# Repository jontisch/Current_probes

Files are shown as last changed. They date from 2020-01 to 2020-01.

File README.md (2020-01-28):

# hall-effect-sensor
A Hall Effect measurement system for measuring power/amperage for graphing

This uses the circuit described in the eagle/gerber directory. 
We've used dirtypcbs.com to make them (http://dirtypcbs.com/view.php?share=27748&accesskey=)

The code used is in arduino/src
It is dependant on 
https://github.com/sirleech/TrueRandom
https://github.com/openenergymonitor/EmonLib 
https://github.com/ntruchsess/arduino_uip (which in turn is patched to support sending DHCP Client Identification which is why it is included in arduino/src)

Hall effect sensors used are SCT-013-000.

---------------------------------------------

IMPORTANT!!

When running on a 2k SRAM AVR (most arduinos) you will need to tweak the serial RX/TX buffers.
This can be found in Arduino/hardware/arduino/avr/cores/arduino/HardwareSerial.h

Just change 
#define SERIAL_TX_BUFFER_SIZE 64
to 
#define SERIAL_TX_BUFFER_SIZE 8

and 

#define SERIAL_RX_BUFFER_SIZE 64
to
#define SERIAL_RX_BUFFER_SIZE 8

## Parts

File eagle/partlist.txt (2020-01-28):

Partlist

Exported from current.sch at 2016-11-06 10:24

EAGLE Version 7.7.0 Copyright (c) 1988-2016 CadSoft

Assembly variant: 

Part     Value              Device             Package               Library             Sheet

C1       10uF               CAP_POLPTH1        CPOL-RADIAL-100UF-25V SparkFun-Passives   1
C2       10uF               CAP_POLPTH2        CPOL-RADIAL-10UF-25V  SparkFun-Capacitors 1
C3       22pF               C5/2.5             C5B2.5                capacitor-wima      1
C4       22pF               C5/2.5             C5B2.5                capacitor-wima      1
C5       10uF               CAP_POLPTH1        CPOL-RADIAL-100UF-25V SparkFun-Passives   1
C6       10uF               CAP_POLPTH1        CPOL-RADIAL-100UF-25V SparkFun-Passives   1
H1       MOUNT-PAD-ROUND3.6 MOUNT-PAD-ROUND3.6 3,6-PAD               holes               1
J1       USB-MICROB         USB-MICROB         USB-MICROB            SparkFun-Connectors 1
J2       3-pol              AUDIO-JACKPTH      AUDIO-JACK            SparkFun-Connectors 1
J3       3-pol              AUDIO-JACKPTH      AUDIO-JACK            SparkFun-Connectors 1
J4       3-pol              AUDIO-JACKPTH      AUDIO-JACK            SparkFun-Connectors 1
LED1     5mm green          LED5MM             LED5MM                led                 1
Q1       16MHz              XTAL/S             QS                    special             1
R1       33                 R-US_0204/5        0204/5                resistor            1
R2       10K                R-US_0204/5        0204/5                resistor            1
R3       10K                R-US_0204/5        0204/5                resistor            1
R4       33                 R-US_0204/5        0204/5                resistor            1
R5       10K                R-US_0204/5        0204/5                resistor            1
R6       10K                R-US_0204/5        0204/5                resistor            1
R7       33                 R-US_0204/5        0204/5                resistor            1
R8       10K                R-US_0204/5        0204/5                resistor            1
R9       10K                R-US_0204/5        0204/5                resistor            1
R10      10K                R-US_0204/5        0204/5                resistor            1
R11      10K                R-US_0204/5        0204/5                resistor            1
R12      10K                R-US_0204/5        0204/5                resistor            1
R13      180                R-US_0204/5        0204/5                resistor            1
R14      100                R-US_0204/5        0204/5                resistor            1
R15      470                R-US_0204/5        0204/5                resistor            1
R16      100                R-US_0204/5        0204/5                resistor            1
R17      10K                R-US_0204/5        0204/5                resistor            1
R18      10K                R-US_0204/5        0204/5                resistor            1
SV1                         MA03-2             MA03-2                con-lstb            1
SV2                         MA05-2             MA05-2                con-lstb            1
SV3      rgb-led            MA04-1             MA04-1                con-lstb            1
SW1                         SW_DIP-2           EDG-02                special             1
U1       ATMEGA328P_PDIP    ATMEGA328P_PDIP    DIL28-3               SparkFun-DigitalIC  1

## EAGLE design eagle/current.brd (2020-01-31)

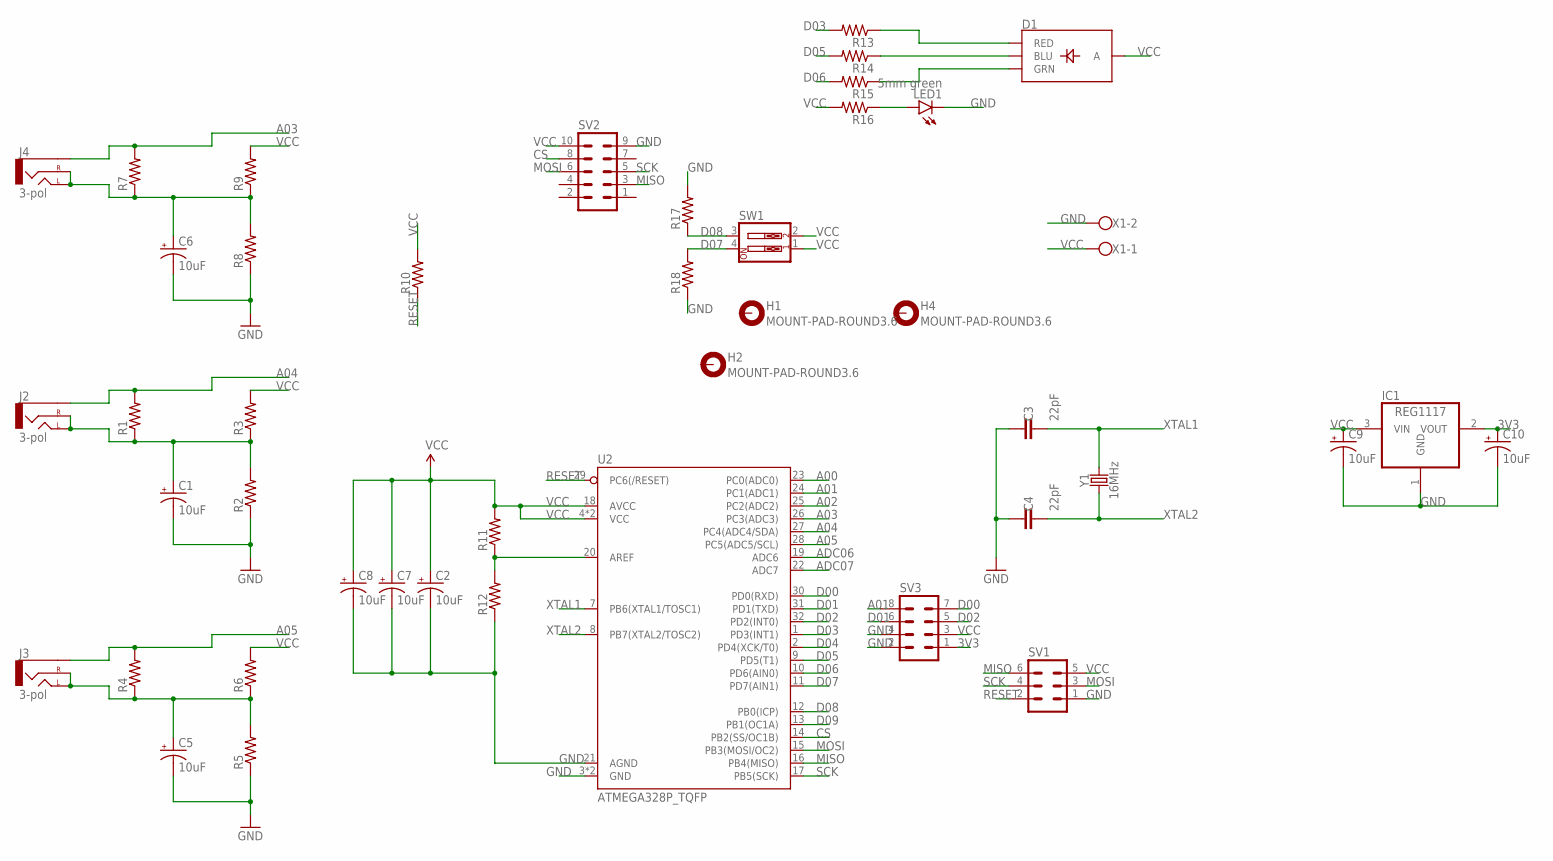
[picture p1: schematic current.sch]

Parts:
C1, C2, C5, C6, C7, C8, C9, C10: 10uF; EIA3216
C3, C4: 22pF; 0805
D1: LED-RGB-CASMD; LED-TRICOLOR-SMD
H1, H2, H4: MOUNT-PAD-ROUND3.6; 3,6-PAD
IC1: REG1117; SOT223
J2, J3, J4: 3-pol; AUDIO-JACK
LED1: 5mm green; CHIPLED_0805
R1, R2, R3, R4, R5, R6, R7, R8, R9, R10, R11, R12, R13, R14, R15, R16, R17, R18: 0805
SV1: MA03-2
SV2: MA05-2
SV3: MA04-2
SW1: SW_DIP-2; EDG-02
U2: ATMEGA328P_TQFP; TQFP32-08
X1: W237-102
Y1: 16MHz; CRYSTAL-SMD-3.2X2.5MM

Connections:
3V3: C10.+, IC1.2 (VOUT), SV3.1
A00: U2.23 (PC0(ADC0))
A01: SV3.8, U2.24 (PC1(ADC1))
A02: U2.25 (PC2(ADC2))
A03: J4.SLEEVE, R7.2, U2.26 (PC3(ADC3))
A04: J2.SLEEVE, R1.2, U2.27 (PC4(ADC4/SDA))
A05: J3.SLEEVE, R4.2, U2.28 (PC5(ADC5/SCL))
ADC06: U2.19 (ADC6)
ADC07: U2.22 (ADC7)
CS: SV2.8, U2.14 (PB2(SS/OC1B))
D00: SV3.7, U2.30 (PD0(RXD))
D01: SV3.6, U2.31 (PD1(TXD))
D02: SV3.5, U2.32 (PD2(INT0))
D03: R13.2, U2.1 (PD3(INT1))
D04: U2.2 (PD4(XCK/T0))
D05: R14.2, U2.9 (PD5(T1))
D06: R15.2, U2.10 (PD6(AIN0))
D07: R18.2, SW1.4, U2.11 (PD7(AIN1))
D08: R17.1, SW1.3, U2.12 (PB0(ICP))
D09: U2.13 (PB1(OC1A))
GND: C1.-, C2.-, C3.1, C4.1, C5.-, C6.-, C7.-, C8.-, C9.-, C10.-, IC1.1 (GND), LED1.C, R2.1, R5.1, R8.1, R12.1, R17.2, R18.1, SV1.1, SV2.9, SV3.2, SV3.4, U2.3 (GND), U2.5 (GND), U2.21 (AGND), X1.2
MISO: SV1.6, SV2.3, U2.16 (PB4(MISO))
MOSI: SV1.3, SV2.6, U2.15 (PB3(MOSI/OC2))
unnamed: C5.+, J3.RING (RIGHT), J3.TIP (LEFT), R4.1, R5.2, R6.1
unnamed: C1.+, J2.RING (RIGHT), J2.TIP (LEFT), R1.1, R2.2, R3.1
unnamed: C6.+, J4.RING (RIGHT), J4.TIP (LEFT), R7.1, R8.2, R9.1
unnamed: D1.R (RED), R13.1
unnamed: R11.1, R12.2, U2.20 (AREF)
unnamed: D1.B (BLU), R14.1
unnamed: D1.G (GRN), R15.1
unnamed: LED1.A, R16.1
RESET: R10.1, SV1.2, U2.29 (PC6(/RESET))
SCK: SV1.4, SV2.5, U2.17 (PB5(SCK))
VCC: C2.+, C7.+, C8.+, C9.+, D1.A, IC1.3 (VIN), R3.2, R6.2, R9.2, R10.2, R11.2, R16.2, SV1.5, SV2.10, SV3.3, SW1.1, SW1.2, U2.4 (VCC), U2.6 (VCC), U2.18 (AVCC), X1.1
XTAL1: C3.2, U2.7 (PB6(XTAL1/TOSC1)), Y1.3 (2)
XTAL2: C4.2, U2.8 (PB7(XTAL2/TOSC2)), Y1.1

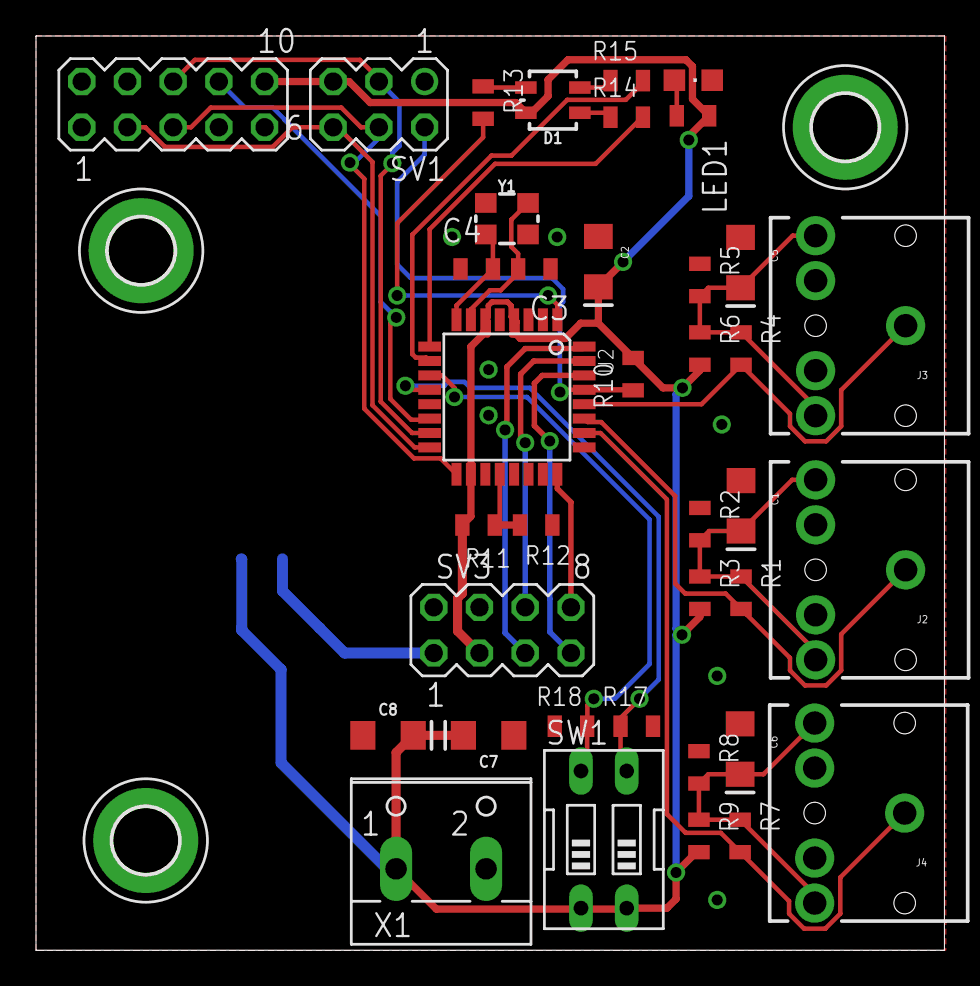
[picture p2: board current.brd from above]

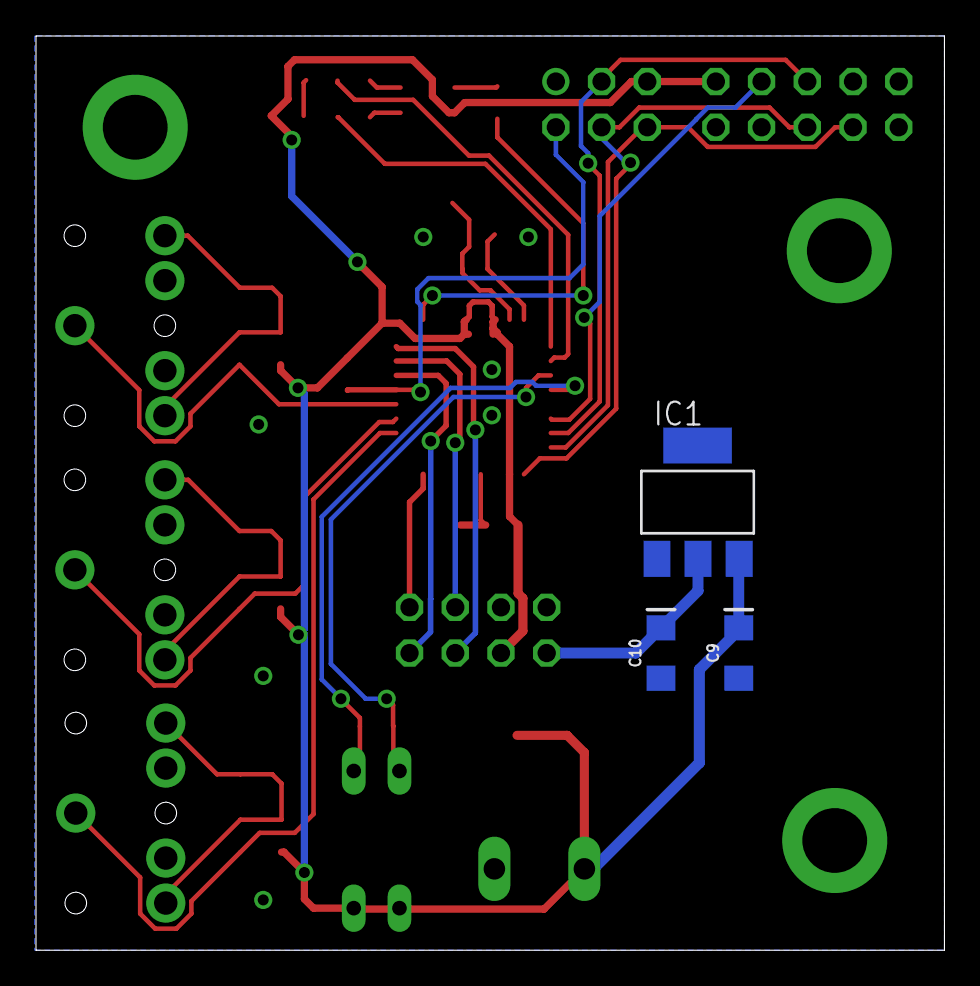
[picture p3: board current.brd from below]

Board: 2 copper layers, 50.5 x 50.8 mm, 44 parts (3 on the bottom side), 30 nets.

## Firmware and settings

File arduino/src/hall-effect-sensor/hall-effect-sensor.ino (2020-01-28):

#include <Dhcp.h>
#include <Dns.h>
#include <avr/pgmspace.h>
#include <ethernet_comp.h>
#include <UIPClient.h>
#include <UIPEthernet.h>
#include <UIPServer.h>
#include <UIPUdp.h>
#include <EmonLib.h>
#include <EEPROM.h>
#include <TrueRandom.h>
// Sample data for the mac address generation
#define samplePin 0
// Calibration value for the SCT-013-000s
#define ACcalibrationValue 22
#define DCcalibrationValue 22
#define voltage 230
#define ERROR (RGB){ HIGH, LOW, LOW };
#define LOADING (RGB){ HIGH, HIGH, LOW };
#define OK (RGB){ LOW, HIGH, LOW };
#define F_CPU 16000000UL

struct RGB {
  byte r;
  byte g;
  byte b;
};

typedef struct {
  EnergyMonitor one;
  EnergyMonitor two;
  EnergyMonitor three;
} Sensors;

RGB LED = ERROR;
static byte mac[6] = { 0x02, 0x00, 0x00, 0x00, 0x00, 0x00 };
unsigned long previous = millis();
unsigned long current = millis();

Sensors sensors;
EthernetServer server = EthernetServer(80);

void generateMacAddress() {
  if (EEPROM.read(1) == '#') {
    for (int i = 4; i < 6; i++) {
      mac[i] = EEPROM.read(i);
    }
  } else {
    randomSeed(analogRead(samplePin));
    for (int i = 4; i < 6; i++) {
      mac[i] = random(0, 255);
      EEPROM.write(i, mac[i]);
    }
    EEPROM.write(1, '#');
  }
}

void initializeRGBdiode() {
  pinMode(3, OUTPUT);
  digitalWrite(3, LOW);
  pinMode(5, OUTPUT);
  digitalWrite(5, LOW);
  pinMode(6, OUTPUT);
  digitalWrite(6, LOW);
  setRGBLEDColor();
}

void setRGBLEDColor() {
  digitalWrite(3, LED.r);
  digitalWrite(5, LED.g);
  digitalWrite(6, LED.b);
}

void blinkRGB() {
  for (int i = 0; i < 10; i++) {
    if (i % 2 == 0) {
      digitalWrite(3, HIGH);
      digitalWrite(5, HIGH);
      digitalWrite(6, HIGH);
    } else {
      digitalWrite(3, LOW);
      digitalWrite(5, LOW);
      digitalWrite(6, LOW);
    }
    delay(100);
  }
}

void setup () {
  Serial.begin(57600);
  initializeRGBdiode();
  pinMode(7, INPUT);
  pinMode(8, INPUT);
  if (digitalRead(7) && digitalRead(8)) { 
    for (int i = 0 ; i < EEPROM.length() ; i++) {
      EEPROM.write(i, 0);
    }
    blinkRGB();
  }

  generateMacAddress();

  if (Ethernet.begin(mac) == 0) {
    LED = ERROR;
    setRGBLEDColor();
  }
  server.begin();

  configureSensors();
  LED = OK;
  setRGBLEDColor();
}

void configureSensors() {
  if (digitalRead(7) && !digitalRead(8)) {
    sensors.one.current(3, DCcalibrationValue);
    sensors.two.current(5, DCcalibrationValue);
    sensors.three.current(4, DCcalibrationValue);
  } else {
    sensors.one.current(3, ACcalibrationValue);
    sensors.two.current(5, ACcalibrationValue);
    sensors.three.current(4, ACcalibrationValue);
  }
}

int readSensor(int sensor) {
  switch (sensor) {
    case 1:
      return sensors.one.calcIrms(1480) * voltage;
      break;
    case 2:
      return sensors.two.calcIrms(1480) * voltage;
      break;
    case 3:
      return sensors.three.calcIrms(1480) * voltage;
      break;
  }
}
char* intToCharFloat(int value) {
  char *buf = (char *) malloc(sizeof(char) * 6);
  dtostrf(value/100.0, 4, 2, buf);
  return buf;
}

void loop() {
  /* Ugly hack to solve that it goes bad after >2000 seconds of requests */
  current = millis();
  if (current-previous > 30000) {
    Enc28J60.init(mac);
    previous = millis();
  }
  setRGBLEDColor();
  Ethernet.maintain();

  EthernetClient client = server.available();
  if (client == true) {
    char reply[110];
    char* sensor1_value = intToCharFloat(readSensor(1));
    char* sensor2_value = intToCharFloat(readSensor(2));
    char* sensor3_value = intToCharFloat(readSensor(3));
    
    server.println(F("HTTP/1.1 200 OK\r\nContent-Type: text/plain\r\nConnection: Closed\r\n"));
    sprintf(reply, "uptime %lu\ncurrent{sensor=\"1\"} %s\ncurrent{sensor=\"2\"} %s\ncurrent{sensor=\"3\"} %s\n", millis()/1000, sensor1_value, sensor2_value, sensor3_value);
    server.print(reply);
    client.stop();
    free(sensor1_value);
    free(sensor2_value);
    free(sensor3_value);
  }
}

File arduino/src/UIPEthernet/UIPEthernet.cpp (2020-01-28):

/*
 UIPEthernet.cpp - Arduino implementation of a uIP wrapper class.
 Copyright (c) 2013 Norbert Truchsess <norbert.truchsess@t-online.de>
 All rights reserved.

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
 You should have received a copy of the GNU General Public License
 along with this program.  If not, see <http://www.gnu.org/licenses/>.
  */

#include <Arduino.h>
#include "UIPEthernet.h"
#include "utility/Enc28J60Network.h"

#if(defined UIPETHERNET_DEBUG || defined UIPETHERNET_DEBUG_CHKSUM)
#include "HardwareSerial.h"
#endif

#include "UIPUdp.h"

extern "C"
{
#include "utility/uip-conf.h"
#include "utility/uip.h"
#include "utility/uip_arp.h"
#include "utility/uip_timer.h"
}

#define ETH_HDR ((struct uip_eth_hdr *)&uip_buf[0])

memhandle UIPEthernetClass::in_packet(NOBLOCK);
memhandle UIPEthernetClass::uip_packet(NOBLOCK);
uint8_t UIPEthernetClass::uip_hdrlen(0);
uint8_t UIPEthernetClass::packetstate(0);

IPAddress UIPEthernetClass::_dnsServerAddress;
DhcpClass* UIPEthernetClass::_dhcp(NULL);

unsigned long UIPEthernetClass::periodic_timer;

// Because uIP isn't encapsulated within a class we have to use global
// variables, so we can only have one TCP/IP stack per program.

UIPEthernetClass::UIPEthernetClass()
{
}

#if UIP_UDP
int
UIPEthernetClass::begin(const uint8_t* mac)
{
  static DhcpClass s_dhcp;
  _dhcp = &s_dhcp;

  // Initialise the basic info
  init(mac);

  // Now try to get our config info from a DHCP server
  int ret = _dhcp->beginWithDHCP((uint8_t*)mac);
  if(ret == 1)
  {
    // We've successfully found a DHCP server and got our configuration info, so set things
    // accordingly
    configure(_dhcp->getLocalIp(),_dhcp->getDnsServerIp(),_dhcp->getGatewayIp(),_dhcp->getSubnetMask());
  }
  return ret;
}
#endif

void
UIPEthernetClass::begin(const uint8_t* mac, IPAddress ip)
{
  IPAddress dns = ip;
  dns[3] = 1;
  begin(mac, ip, dns);
}

void
UIPEthernetClass::begin(const uint8_t* mac, IPAddress ip, IPAddress dns)
{
  IPAddress gateway = ip;
  gateway[3] = 1;
  begin(mac, ip, dns, gateway);
}

void
UIPEthernetClass::begin(const uint8_t* mac, IPAddress ip, IPAddress dns, IPAddress gateway)
{
  IPAddress subnet(255, 255, 255, 0);
  begin(mac, ip, dns, gateway, subnet);
}

void
UIPEthernetClass::begin(const uint8_t* mac, IPAddress ip, IPAddress dns, IPAddress gateway, IPAddress subnet)
{
  init(mac);
  configure(ip,dns,gateway,subnet);
}

int UIPEthernetClass::maintain(){
  tick();
  int rc = DHCP_CHECK_NONE;
#if UIP_UDP
  if(_dhcp != NULL){
    //we have a pointer to dhcp, use it
    rc = _dhcp->checkLease();
    switch ( rc ){
      case DHCP_CHECK_NONE:
        //nothing done
        break;
      case DHCP_CHECK_RENEW_OK:
      case DHCP_CHECK_REBIND_OK:
        //we might have got a new IP.
        configure(_dhcp->getLocalIp(),_dhcp->getDnsServerIp(),_dhcp->getGatewayIp(),_dhcp->getSubnetMask());
        break;
      default:
        //this is actually a error, it will retry though
        break;
    }
  }
  return rc;
#endif
}

IPAddress UIPEthernetClass::localIP()
{
  IPAddress ret;
  uip_ipaddr_t a;
  uip_gethostaddr(a);
  return ip_addr_uip(a);
}

IPAddress UIPEthernetClass::subnetMask()
{
  IPAddress ret;
  uip_ipaddr_t a;
  uip_getnetmask(a);
  return ip_addr_uip(a);
}

IPAddress UIPEthernetClass::gatewayIP()
{
  IPAddress ret;
  uip_ipaddr_t a;
  uip_getdraddr(a);
  return ip_addr_uip(a);
}

IPAddress UIPEthernetClass::dnsServerIP()
{
  return _dnsServerAddress;
}

void
UIPEthernetClass::tick()
{
  if (in_packet == NOBLOCK)
    {
      in_packet = Enc28J60Network::receivePacket();
#ifdef UIPETHERNET_DEBUG
      if (in_packet != NOBLOCK)
        {
          Serial.print(F("--------------\nreceivePacket: "));
          Serial.println(in_packet);
        }
#endif
    }
  if (in_packet != NOBLOCK)
    {
      packetstate = UIPETHERNET_FREEPACKET;
      uip_len = Enc28J60Network::blockSize(in_packet);
      if (uip_len > 0)
        {
          Enc28J60Network::readPacket(in_packet,0,(uint8_t*)uip_buf,UIP_BUFSIZE);
          if (ETH_HDR ->type == HTONS(UIP_ETHTYPE_IP))
            {
              uip_packet = in_packet; //required for upper_layer_checksum of in_packet!
#ifdef UIPETHERNET_DEBUG
              Serial.print(F("readPacket type IP, uip_len: "));
              Serial.println(uip_len);
#endif
              uip_arp_ipin();
              uip_input();
              if (uip_len > 0)
                {
                  uip_arp_out();
                  network_send();
                }
            }
          else if (ETH_HDR ->type == HTONS(UIP_ETHTYPE_ARP))
            {
#ifdef UIPETHERNET_DEBUG
              Serial.print(F("readPacket type ARP, uip_len: "));
              Serial.println(uip_len);
#endif
              uip_arp_arpin();
              if (uip_len > 0)
                {
                  network_send();
                }
            }
        }
      if (in_packet != NOBLOCK && (packetstate & UIPETHERNET_FREEPACKET))
        {
#ifdef UIPETHERNET_DEBUG
          Serial.print(F("freeing packet: "));
          Serial.println(in_packet);
#endif
          Enc28J60Network::freePacket();
          in_packet = NOBLOCK;
        }
    }

  unsigned long now = millis();

#if UIP_CLIENT_TIMER >= 0
  boolean periodic = (long)( now - periodic_timer ) >= 0;
  for (int i = 0; i < UIP_CONNS; i++)
    {
#else
  if ((long)( now - periodic_timer ) >= 0)
    {
      periodic_timer = now + UIP_PERIODIC_TIMER;

      for (int i = 0; i < UIP_CONNS; i++)
        {
#endif
      uip_conn = &uip_conns[i];
#if UIP_CLIENT_TIMER >= 0
      if (periodic)
        {
#endif
          uip_process(UIP_TIMER);
#if UIP_CLIENT_TIMER >= 0
        }
      else
        {
          if ((long)( now - ((uip_userdata_t*)uip_conn->appstate)->timer) >= 0)
            uip_process(UIP_POLL_REQUEST);
          else
            continue;
        }
#endif
        // If the above function invocation resulted in data that
        // should be sent out on the Enc28J60Network, the global variable
        // uip_len is set to a value > 0.
      if (uip_len > 0)
        {
          uip_arp_out();
          network_send();
        }
    }
#if UIP_CLIENT_TIMER >= 0
  if (periodic)
    {
      periodic_timer = now + UIP_PERIODIC_TIMER;
#endif
#if UIP_UDP
      for (int i = 0; i < UIP_UDP_CONNS; i++)
        {
          uip_udp_periodic(i);
          // If the above function invocation resulted in data that
          // should be sent out on the Enc28J60Network, the global variable
          // uip_len is set to a value > 0. */
          if (uip_len > 0)
            {
              UIPUDP::_send((uip_udp_userdata_t *)(uip_udp_conns[i].appstate));
            }
        }
#endif /* UIP_UDP */
    }
}
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

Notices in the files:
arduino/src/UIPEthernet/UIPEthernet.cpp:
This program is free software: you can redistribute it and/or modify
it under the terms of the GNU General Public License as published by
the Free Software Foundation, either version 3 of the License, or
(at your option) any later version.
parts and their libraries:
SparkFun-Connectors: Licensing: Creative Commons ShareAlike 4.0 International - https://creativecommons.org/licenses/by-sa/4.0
